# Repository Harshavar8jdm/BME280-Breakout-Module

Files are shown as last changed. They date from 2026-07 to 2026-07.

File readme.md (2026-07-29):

# BME280 Environmental Sensor Breakout Module

An ultra-compact ($12 \times 10\,\text{mm}$) hardware breakout board for the **Bosch BME280** humidity, pressure, and temperature sensor. Designed in KiCad, this board breaks out the essential I2C signals to a standard $2.54\,\text{mm}$ header for seamless integration into low-power embedded systems and microcontroller prototyping.

## 3D Board Renders

| Top View | Bottom View |
| :---: | :---: |
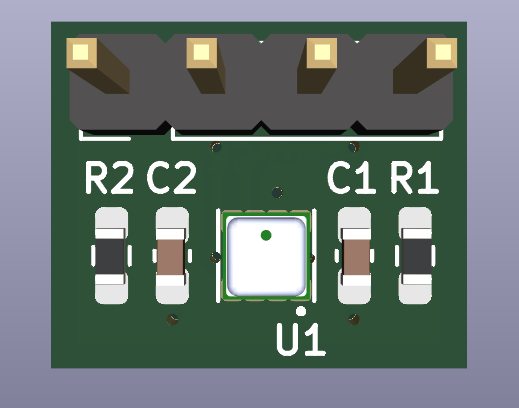
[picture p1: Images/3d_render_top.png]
3D Render Top
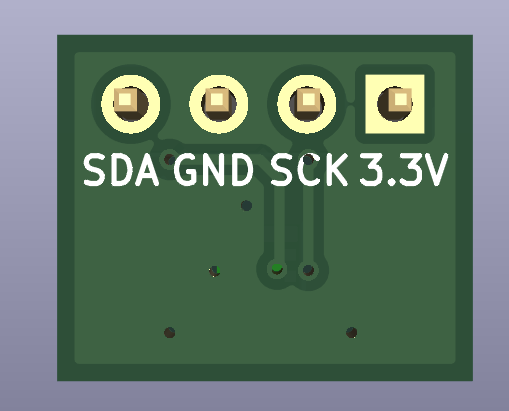
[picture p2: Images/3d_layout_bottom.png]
3D Render Bottom
|  |  |

---

## Technical Specifications

| Parameter | Value / Description |
| :--- | :--- |
| **Dimensions** | $12\,\text{mm} \times 10\,\text{mm}$ |
| **Supply Voltage ($V_{DD}$ / $V_{DDIO}$)** | $3.3\,\text{V}$ DC |
| **Communication Interface** | I2C (Hardwired) |
| **I2C Slave Address** | `0x77` (`SDO` pulled HIGH to $V_{DDIO}$) |
| **I2C Pull-Up Resistors** | $2.2\,\text{k}\Omega$ (Supports Standard & Fast Mode) |
| **Header Pitch** | $2.54\,\text{mm}$ ($100\,\text{mil}$) |
| **Passives Form Factor** | 0603 (1608 Metric) |
| **EDA Software** | KiCad EDA v10.0.4 |

---

## Pinout Configuration

The module features a 4-pin header interface designed for easy breadboard or jumper cable hookup:

| Header Pin | Label | Type | Schematic Net | Description |
| :---: | :--- | :--- | :--- | :--- |
| **1** | `3.3V` | Power | `+3.3V` | Main Power Supply ($3.3\,\text{V}$) |
| **2** | `SCK` | Input | `SCK` / `SCL` | I2C Serial Clock line |
| **3** | `GND` | Power | `GND` | System Ground Reference |
| **4** | `SDA` | I/O | `SDA` | I2C Serial Data line |

> **Note on Crosstalk:** Placing Ground (`GND`) between `SCK` and `SDA` on the physical pin header provides physical shielding against signal crosstalk across external cables.

---

## Schematic & Hardware Design

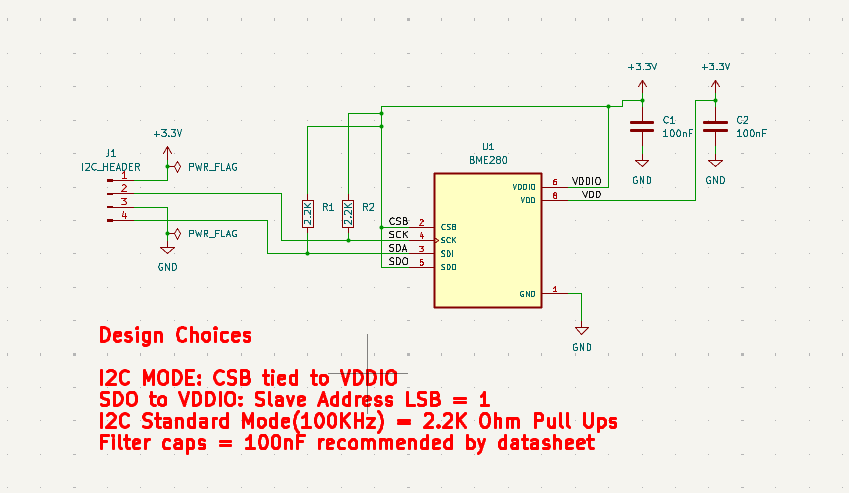
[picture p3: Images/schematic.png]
Schematic Diagram


### Design Choices
* **Hardwired I2C Mode:** Pin 2 (`CSB`) is connected directly to $V_{DDIO}$ ($+3.3\,\text{V}$), permanently selecting the I2C interface protocol and disabling SPI.
* **Slave Address Selection:** Pin 5 (`SDO`) is tied to $V_{DDIO}$, setting the default 7-bit I2C address to **`0x77`**.
* **Bus Termination:** $2.2\,\text{k}\Omega$ pull-up resistors ($R_1, R_2$) are included on both `SDA` and `SCK` lines to guarantee fast rise times ($t_r < 300\,\text{ns}$) for 400 kHz Fast-Mode I2C operation.
* **Power Supply Decoupling:** Dedicated $100\,\text{nF}$ ceramic decoupling capacitors ($C_1, C_2$) are placed close to the $V_{DD}$ and $V_{DDIO}$ power pins to filter high-frequency noise and voltage ripple.

---

## PCB Layout

| Top Layer (F.Cu) | Bottom Layer (B.Cu) | Combined Stackup |
| :---: | :---: | :---: |
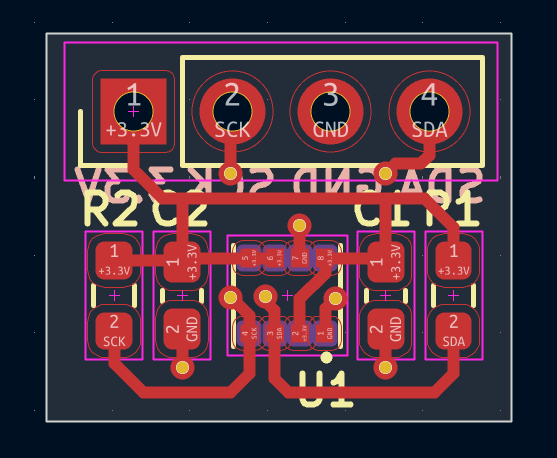
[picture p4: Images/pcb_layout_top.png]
PCB Layout Top
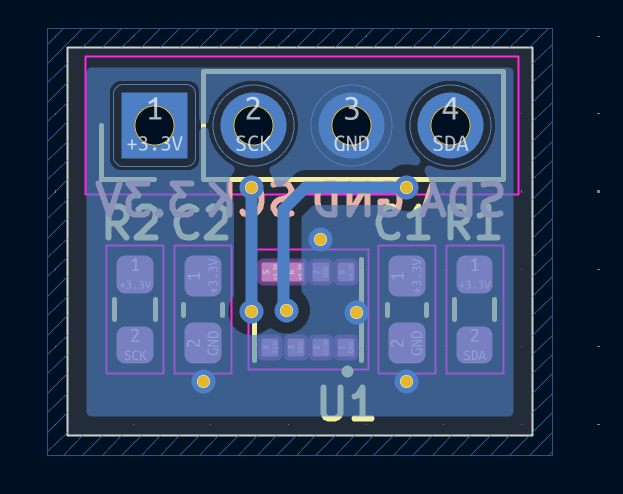
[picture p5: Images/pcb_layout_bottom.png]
PCB Layout Bottom
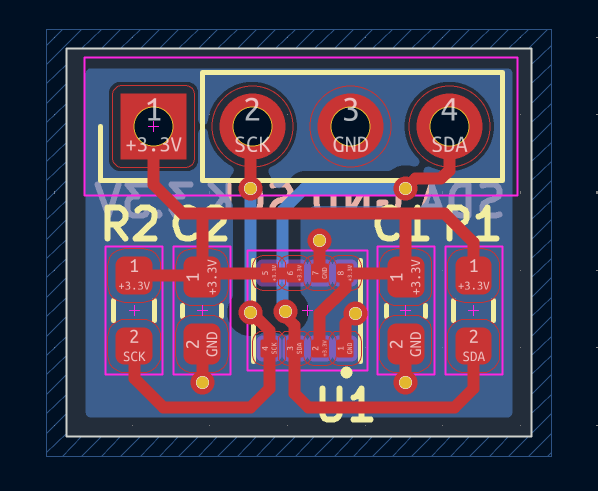
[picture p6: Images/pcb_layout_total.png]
PCB Layout Total
|  |  |  |

---

                                    # Project Documentation

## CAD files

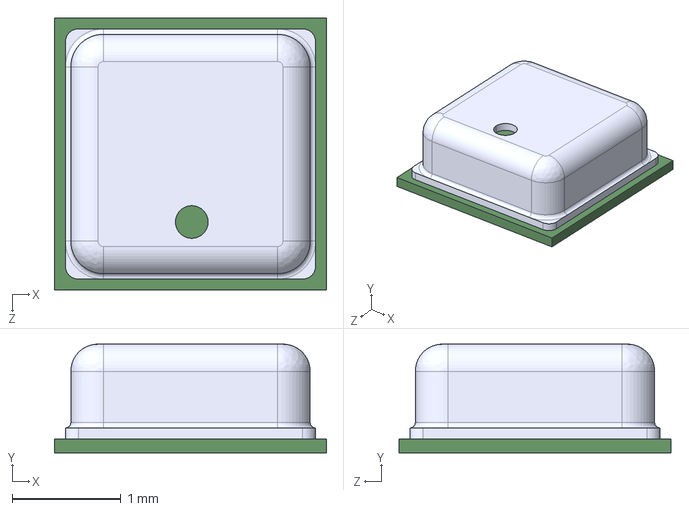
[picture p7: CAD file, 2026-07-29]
ext-libs/BME280--3DModel-STEP-269445.STEP
2.50 x 1.00 x 2.50 mm

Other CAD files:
ext-libs/BME280/BME280.step

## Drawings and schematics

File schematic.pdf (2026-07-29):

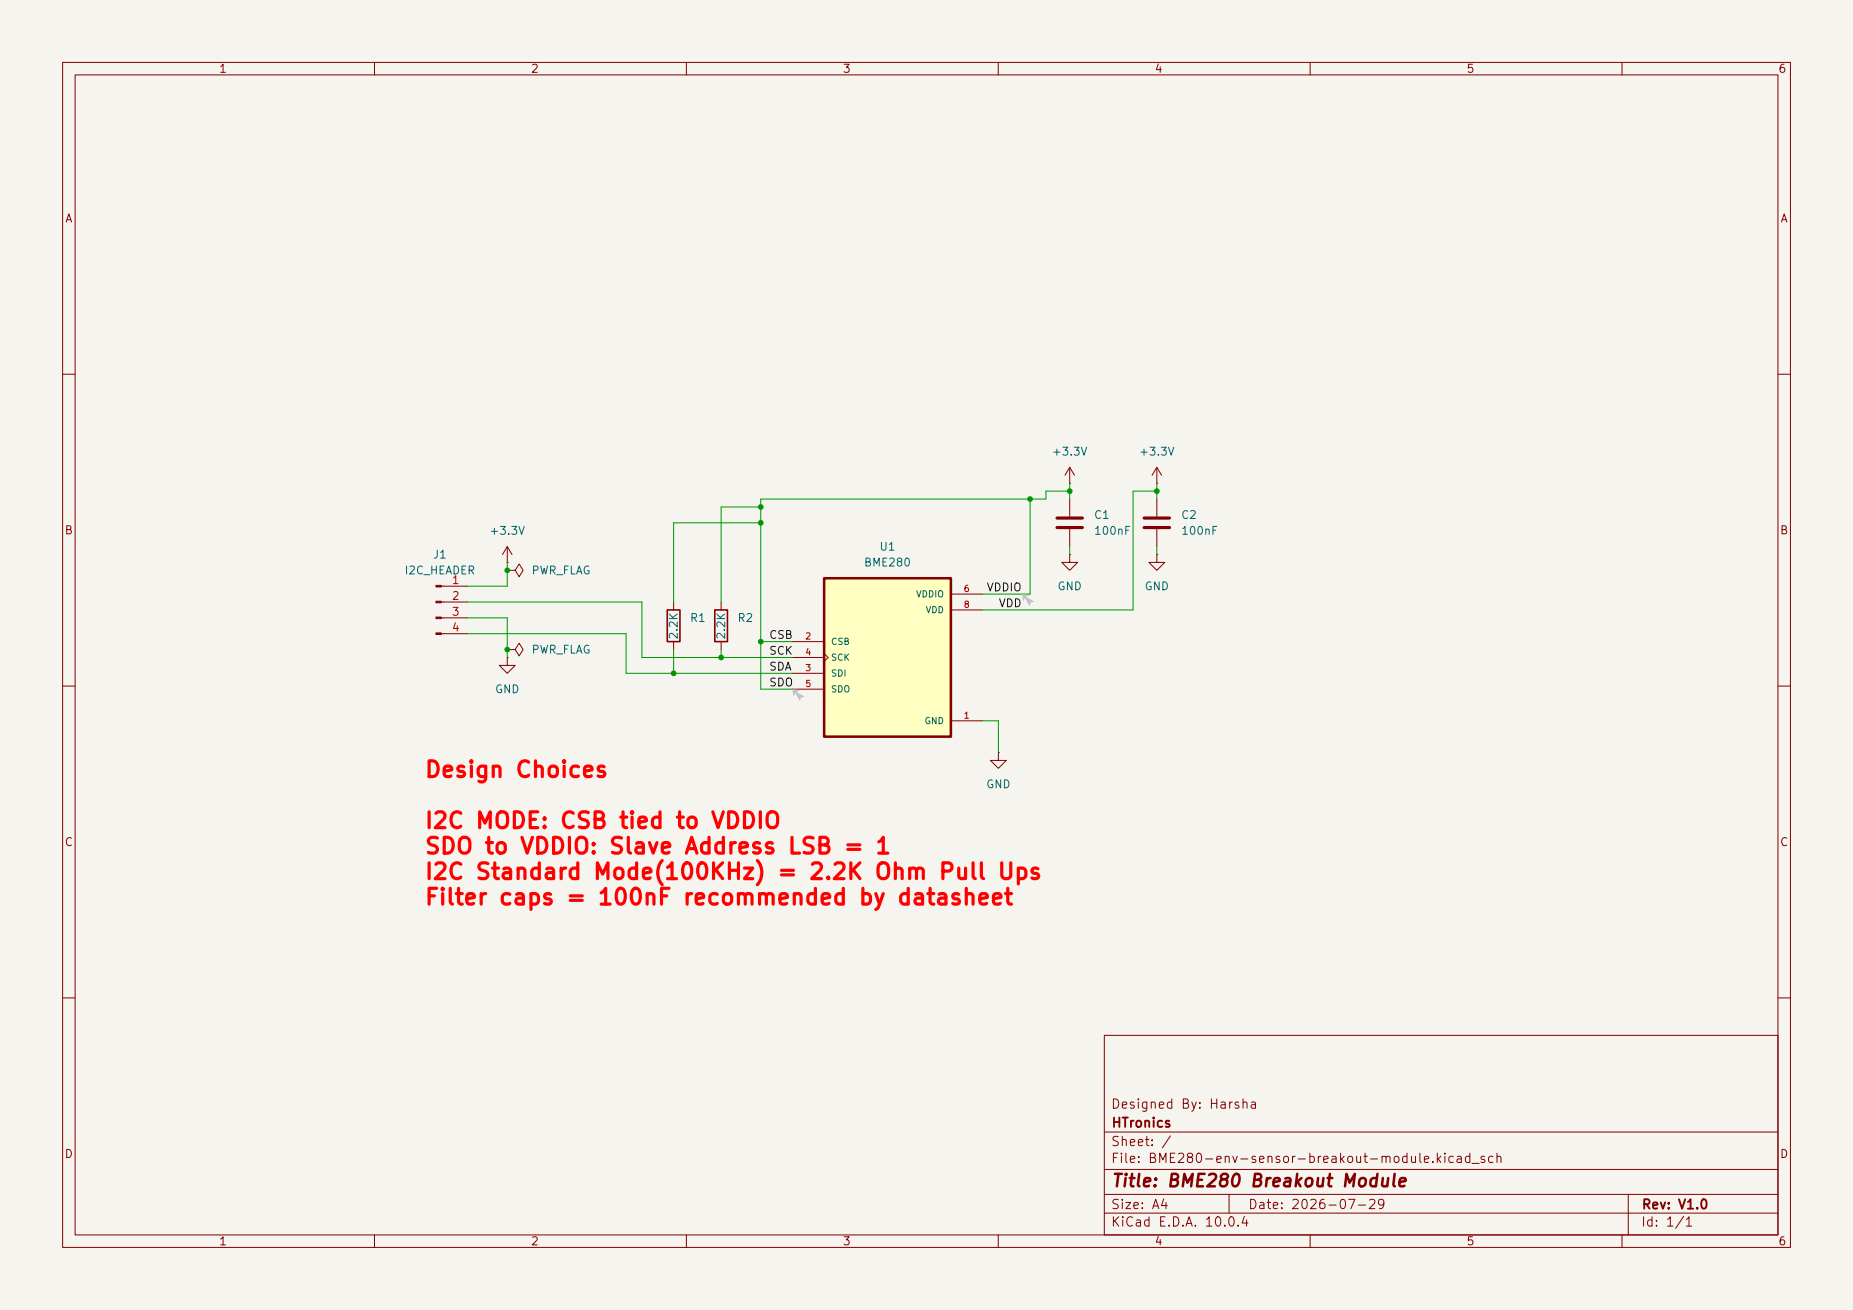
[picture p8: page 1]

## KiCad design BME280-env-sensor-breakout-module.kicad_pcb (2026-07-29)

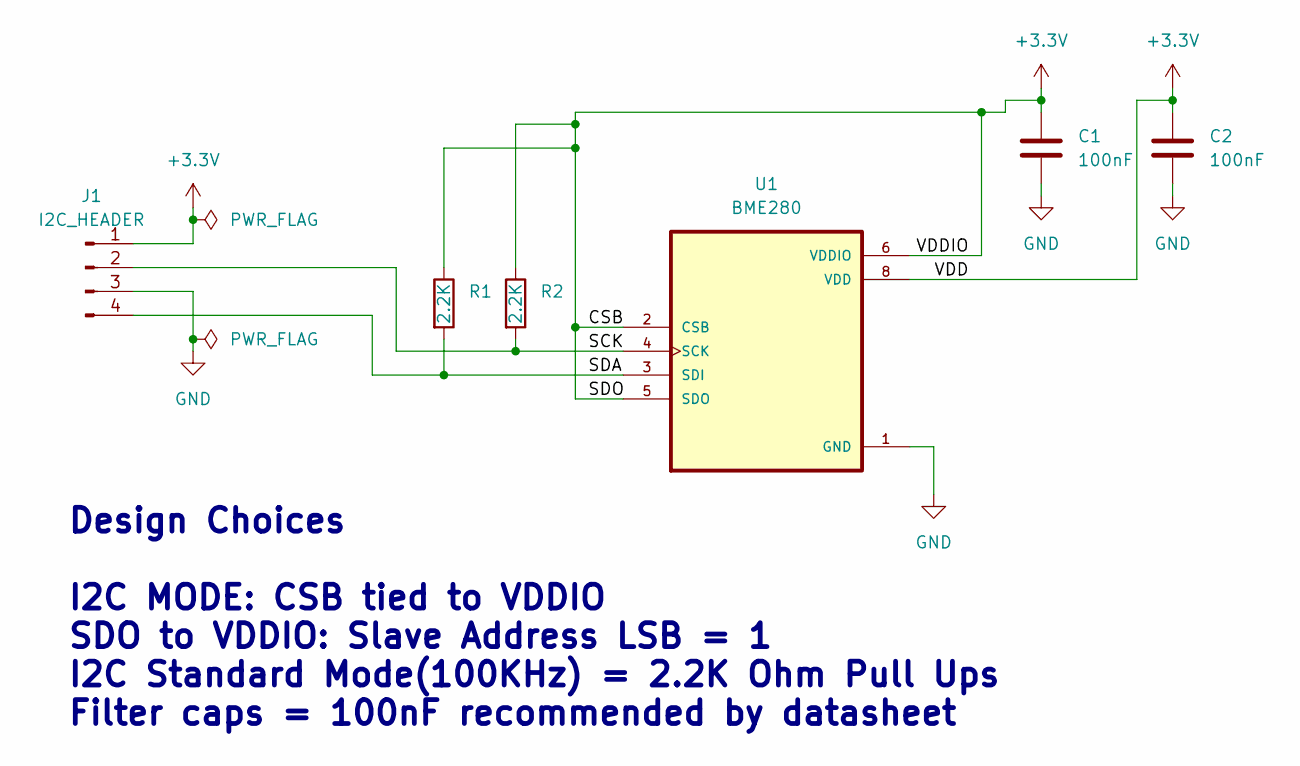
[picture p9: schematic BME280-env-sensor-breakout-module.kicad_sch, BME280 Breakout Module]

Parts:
C1, C2: 100nF; C_0603_1608Metric_Pad1.08x0.95mm_HandSolder
J1: I2C_HEADER; PinHeader_1x04_P2.54mm_Vertical
R1, R2: 2.2K; R_0603_1608Metric_Pad0.98x0.95mm_HandSolder
U1: BME280; PSON65P250X250X100-8N

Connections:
+3.3V: C1.1, C2.1, J1.1, R1.1, R2.1, U1.2 (CSB), U1.5 (SDO), U1.6 (VDDIO), U1.8 (VDD)
/SCK: J1.2, R2.2, U1.4 (SCK)
/SDA: J1.4, R1.2, U1.3 (SDI)
GND: C1.2, C2.2, J1.3, U1.1 (GND), U1.7 (GND)

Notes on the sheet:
Design Choices I2C MODE: CSB tied to VDDIO SDO to VDDIO: Slave Address LSB = 1 I2C Standard Mode(100KHz) = 2.2K Ohm Pull Ups Filter caps = 100nF recommended by datasheet

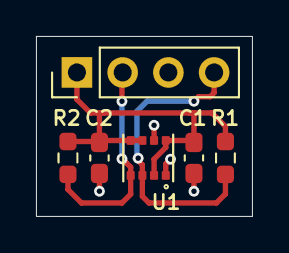
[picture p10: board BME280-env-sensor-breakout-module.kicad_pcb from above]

Board: 2 copper layers, 12.0 x 10.0 mm, 6 parts (0 on the bottom side), 4 nets.

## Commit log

2026-07-29 completed schematic and routing
    [BME280--3DModel-STEP-269445.STEP, BME280-env-sensor-breakout-module.kicad_pcb, BME280-env-sensor-breakout-module.kicad_sch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]
2026-07-29 added images
    [BME280-env-sensor-breakout-module.kicad_pcb]
2026-07-29 schematic pdf
2026-07-29 plotted gerbers
    [BME280-env-sensor-breakout-module-B_Cu.gbr, BME280-env-sensor-breakout-module-B_Mask.gbr, BME280-env-sensor-breakout-module-B_Paste.gbr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]
